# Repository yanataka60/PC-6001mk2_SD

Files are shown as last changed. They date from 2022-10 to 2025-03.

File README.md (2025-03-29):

# PC-6001mk2 MODE1～MODE4にSD-CARDからロード、セーブ機能

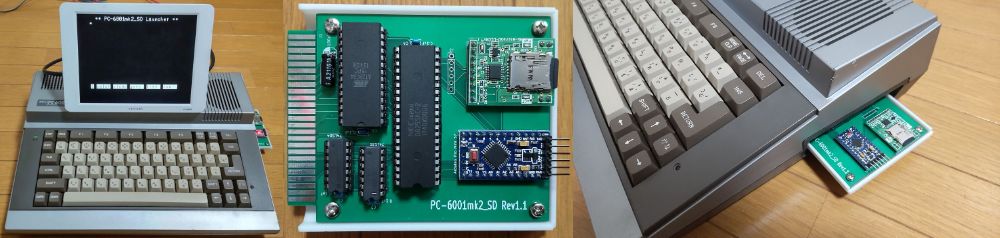
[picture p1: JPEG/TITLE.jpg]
TITLE


　PC-6001mk2の MODE1～MODE4でSD-CARDからロード、セーブ機能を実現するものです。

　対応機種は、PC-6001mk2、PC-6001mk2SR、PC-6601、PC-6601SRです。PC-6601、PC-6601SRはドライブ数切替スイッチは0として使ってください。

　対応しているCMT形式は、P6形式(拡張子はP6、CASのどちらでも大丈夫)とP6T形式です。

　CMTからの読み込み実行に数分掛かっていたゲームも数十秒で実行できます。

　なお、Arduino、ROMへ書き込むための機器が別途必要となります。

　また、本体内のBASIC-ROMを差し替えられるスキルがあればMODE5もSD対応にできます。詳細は、「MODE5対応について」を参照してください。

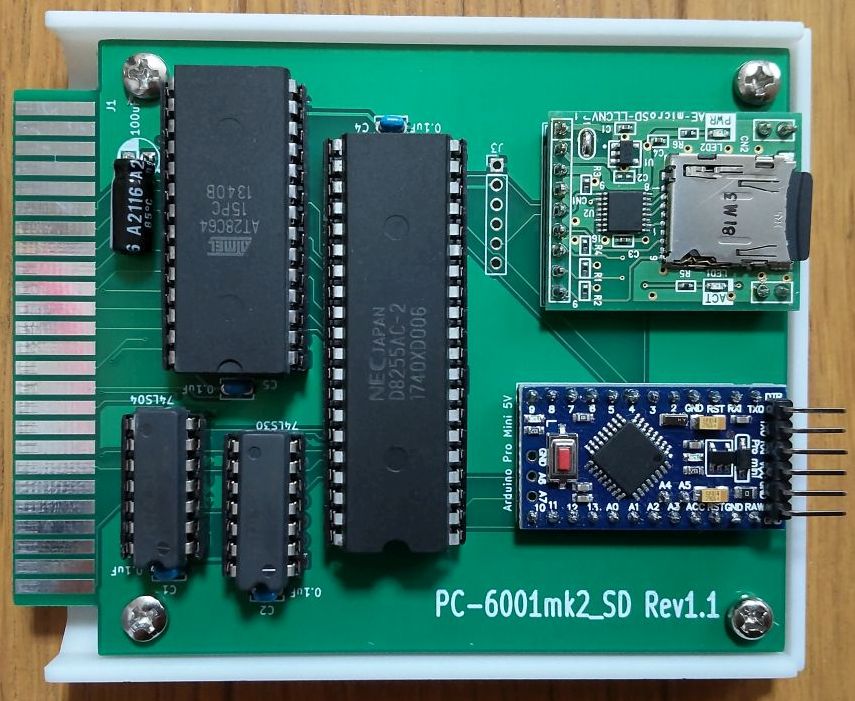
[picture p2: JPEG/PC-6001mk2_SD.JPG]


## 対応できないもの
　MODE1～MODE4については、BASIC-ROMを裏RAMにコピーしCMT関連ルーチンをSD-CARDアクセスに書き換えてSD-CARDへのアクセスを実現しています。

　MODE5についてはBASIC-ROMのCMT関連ルーチンにパッチを当てたROMに差し替えることでSD-CARDへのアクセスを実現していますが、MODE6についてはBASIC-ROMのCMT関連ルーチンが特定できていないためSD-CARDは使えません。

　また、BASIC-ROMのCMT関連ルーチンをコールせず独自ルーチンによりCMTからLOADするソフト（ロードランナー等）も対応できないので途中で止まります。

## 回路図
　KiCadフォルダ内のPC-6001mk2_SD.pdfを参照してください。

[回路図](https://github.com/yanataka60/PC-6001mk2_SD/blob/main/Kicad/PC-6001_mk2_SD.pdf)

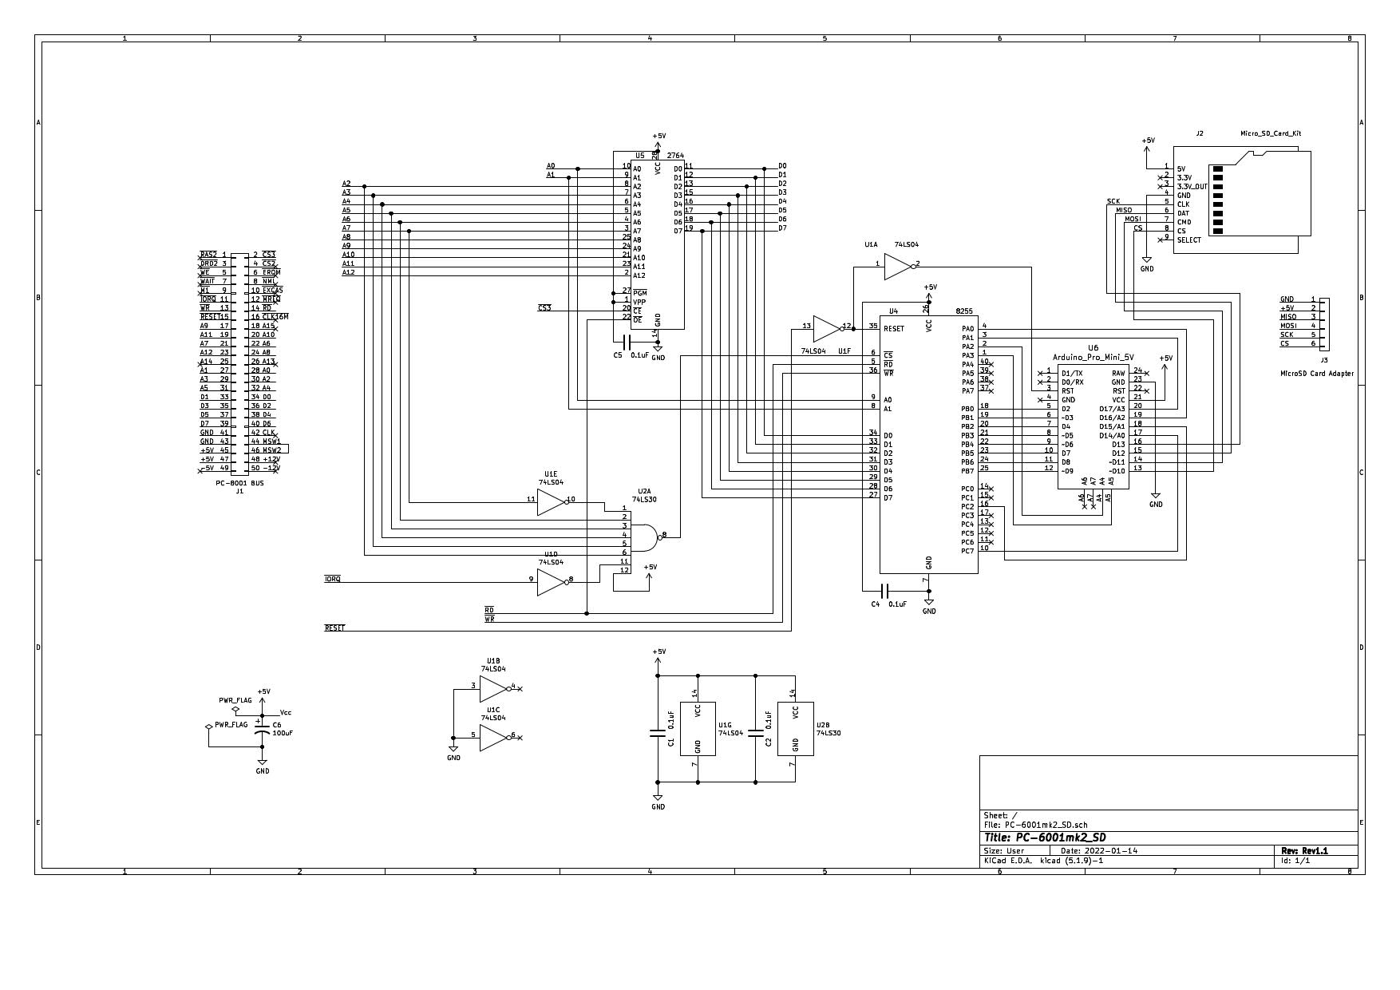
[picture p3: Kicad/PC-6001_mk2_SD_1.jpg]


## 部品
|番号|品名|数量|備考|
| --- | --- | --- | --- |
||J2、J3のいずれか(注1)|||
|J2|Micro_SD_Card_Kit|1|秋月電子通商 AE-microSD-LLCNV (注2)|
|J3|MicroSD Card Adapter|1|Arduino等に使われる5V電源に対応したもの (注4)|
|U1|74LS04|1||
|U2|74LS30|1||
|U4|8255|1||
|U5|2764/28C64相当品|1||
|U6|Arduino_Pro_Mini_5V|1|Atmega328版を使用 168版は不可。(注3)|
|C1 C2 C4 C5|積層セラミックコンデンサ 0.1uF|4||
|C6|電解コンデンサ 16v100uF|1||
||ピンヘッダ|2Pin分|Arduino_Pro_MiniにはA4、A5用のピンヘッダが付いていないため別途調達が必要です 秋月電子通商 PH-1x40SGなど|
||ピンソケット(任意)|26Pin分|Arduino_Pro_Miniを取り外し可能としたい場合に調達します 秋月電子通商 FHU-1x42SGなど|

　　　注1)J2又はJ3のどちらかを選択して取り付けてください。

　　　注2)秋月電子通商　AE-microSD-LLCNVのJ1ジャンパはショートしてください。

　　　注3)Arduino Pro MiniはA4、A5ピンも使っています。

　　　注4)MicroSD Card Adapterを使う場合

　　　　　J3に取り付けます。

　　　　　MicroSD Card Adapterについているピンヘッダを除去してハンダ付けするのが一番確実ですが、J3の穴にMicroSD Card Adapterをぴったりと押しつけ、裏から多めにハンダを流し込むことでハンダ付けをする方法もあります。なお、この方法の時にはしっかりハンダ付けが出来たかテスターで導通を確認しておいた方が安心です。

ハンダ付けに自信のない方はJ2の秋月電子通商　AE-microSD-LLCNVをお使いください。AE-microSD-LLCNVならパワーLED、アクセスLEDが付いています。

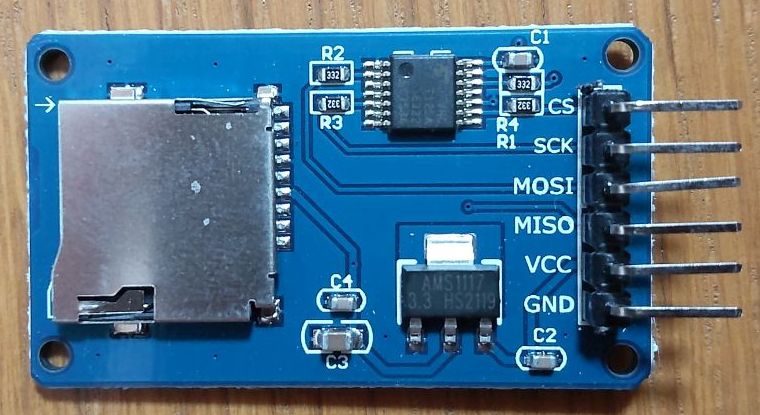
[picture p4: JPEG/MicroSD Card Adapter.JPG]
MicroSD Card Adapter1


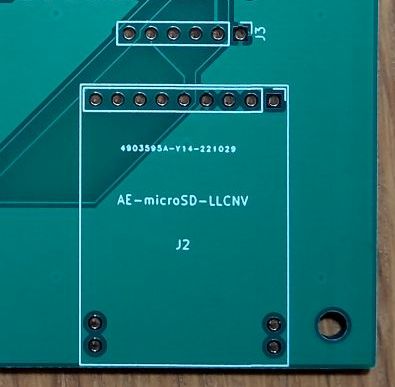
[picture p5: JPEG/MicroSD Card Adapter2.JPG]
MicroSD Card Adapter2


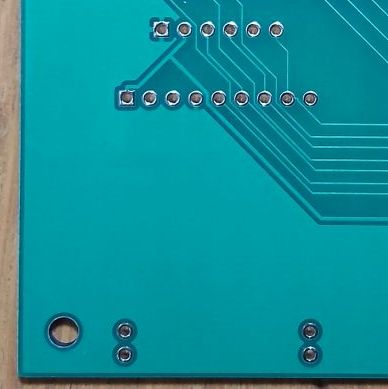
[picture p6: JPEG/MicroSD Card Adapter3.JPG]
MicroSD Card Adapter3


## ROMへの書込み
　Z80フォルダ内のEXT_ROM.binをROMライター(TL866II Plus等)を使って2764又は28C64に書き込みます。

## Arduinoプログラム
　Arduino IDEを使ってArduinoフォルダのPC-6001mk2_SDフォルダ内PC-6001mk2_SD.inoを書き込みます。

　SdFatライブラリを使用しているのでArduino IDEメニューのライブラリの管理からライブラリマネージャを立ち上げて「SdFat」をインストールしてください。

　「SdFat」で検索すれば見つかります。「SdFat」と「SdFat - Adafruit Fork」が見つかりますが「SdFat」のほうを使っています。

注)Arduinoを基板に直付けしている場合、Arduinoプログラムを書き込むときは、カートリッジスロットから抜き、74LS04を外したうえで書き込んでください。

## 接続
　カートリッジスロットに挿入します。

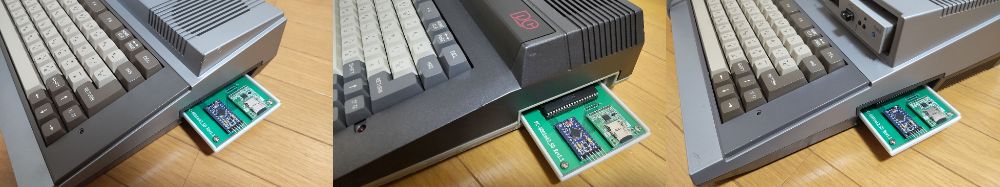
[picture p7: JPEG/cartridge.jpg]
cartridge


　カートリッジスロットへの抜き差しに基板のみでは不便です。

　STLフォルダに基板を載せられるトレイの3Dデータを置いたので出力して使うと便利です。

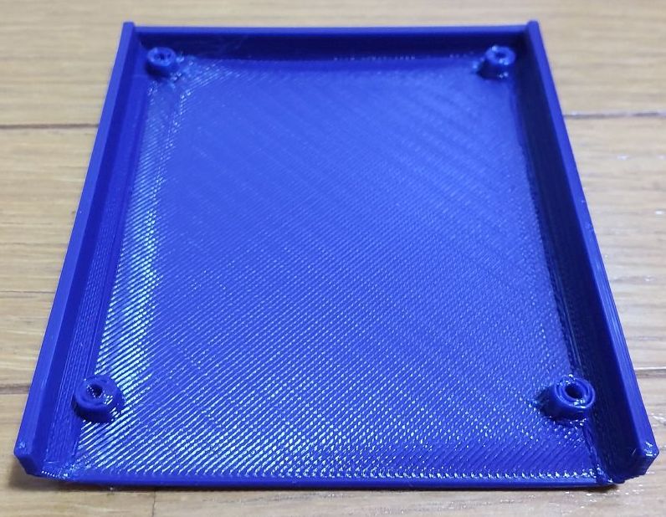
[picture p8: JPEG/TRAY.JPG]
Tray


　PC-6601、PC-6601SRはドライブ数切替スイッチは0として使ってください。

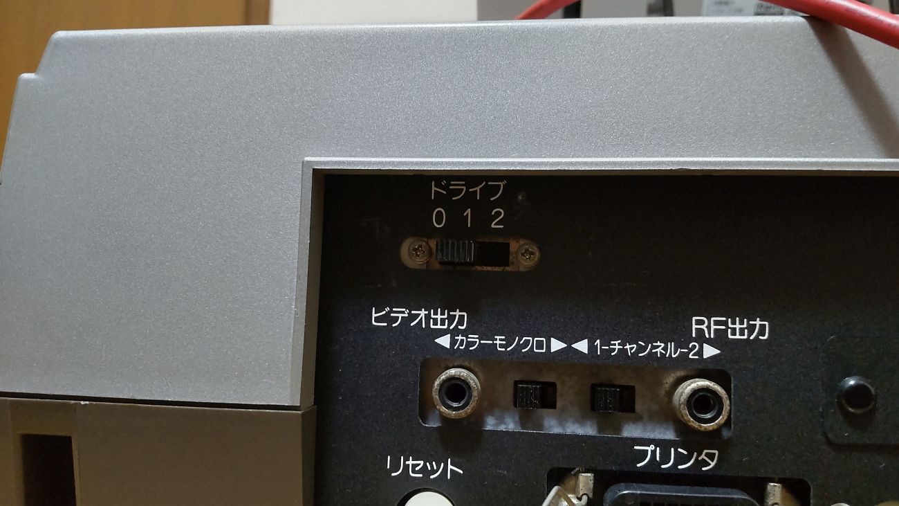
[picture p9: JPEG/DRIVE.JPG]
Drive


## SD-CARD
　出来れば8GB以下のSDカードを用意してください。

　ArduinoのSdFatライブラリは、SD規格(最大2GB)、SDHC規格(2GB～32GB)に対応していますが、SDXC規格(32GB～2TB)には対応していません。

　また、SDHC規格のSDカードであっても32GB、16GBは相性により動作しないものがあるようです。

　FAT16又はFAT32が認識できます。NTFSは認識できません。

　ルートに置かれた拡張子が「.P6T」又は「.CAS」の形式ファイルのみ認識できます。(以外のファイル、フォルダも表示されますがLOAD実行の対象になりません)

　ファイル名は拡張子を除いて32文字まで、ただし半角カタカナ、及び一部の記号はArduinoが認識しないので使えません。パソコンでファイル名を付けるときはアルファベット、数字および空白でファイル名をつけてください。

　起動直後の画面は横32文字表示です。拡張子を含めて27文字以下にしたほうが画面の乱れません。

## 使い方

起動直後は拡張ROMのプログラムが走り、以下のコマンドが使えます。

### Launcherコマンド
#### 1から4までのいずれかの後に[CR]
次に「How Many Pages?(1-4)」と聞いてくるので画面数を入力すると入力された数字のMODEと画面数でSD対応にして起動します。

#### B[CR]
SD対応せずにBASICを起動します。

[STOP]キーと動作は同じです。

#### [STOP]キー
SD対応せずにBASICを起動します。

B[CR]と動作は同じです。

#### F[CR]又はF 文字列[CR]
文字列を入力せずにF[CR]のみ入力するとSD-CARDルートディレクトリにあるファイルの一覧を表示します。

文字列を付けて入力すればSD-CARDルートディレクトリにあるその文字列から始まるファイルの一覧を表示します。

10件表示したところで指示待ちになるので打ち切るならESC又は↑を入力すると打ち切られ、Bキーで前の10件に戻ります。それ以外のキーで次の10件を表示します。

　行頭に「*L 」を付加して表示してあるので実行したいファイルにカーソルキーを合わせて[CR]キーを押すだけでLOAD可能です。

　LOADの挙動については次のLコマンドの記述を参照してください。

　表示される順番は、登録順となりファイル名アルファベッド順などのソートした順で表示することはできません。

##### 例)
　　F[CR]

　　F S[CR]

　　F SP[CR]

#### L DOSファイル名[CR]
指定したDOSフィル名のファイルをSD-CARDからLOADします。

ファイル名の最後の「.P6T」「.CAS」は有っても無くても構いませんが、無い場合は「.P6T」が指定されたものとみなします。

　例)

　　L TEST.P6T -> DOSファイル名「TEST.P6T」を読み込みます。

　　L TEST.CAS -> DOSファイル名「TEST.CAS」を読み込みます。

　　L TEST -> DOSファイル名「TEST.P6T」を読み込みます。

　選択したファイルが「P6T」形式の場合、設定されたMODEと設定されたPagesで起動したうえで自動実行文字列を実行します。

　選択したファイルが「CAS」形式の場合、「Mode?(1-4)」と聞いてくるのでモードを入力、次に「How Many Pages?(1-4)」と聞いてくるので画面数を入力、最後に「Auto Run?(y/c/n)」と聞いてくるので「y」とすれば起動直後にCLOAD[CR]RUN[CR]が実行され、「c」とすればCLOAD[CR]だけが実行、「n」とすれば何も実行されません。

#### 操作上の注意
　~~「SD-CARD INITIALIZE ERROR」と表示されたときは、SD-CARDをいったん抜き再挿入したうえでArduinoをリセットしてください。~~

　~~SD-CARDにアクセスしていない時に電源が入ったままで SD-CARDを抜いた後、再挿入しSD-CARDにアクセスすると「SD-CARD INITIALIZE ERROR」となる場合があります。再挿入した場合にはSD-CARDにアクセスする前にArduinoを必ずリセットしてください。~~

　~~SD-CARDの抜き差しは電源を切った状態で行うほうがより確実です。~~

　(2024.3.12) SD-CARDにアクセスしていない時に電源が入ったままでSD-CARDを抜くと再度SD-CARDを挿入してもSD-CARDにアクセスできない問題を解消しました。(Arduinoを最新版に書き換えてください)

　再度SD-CARDを挿入した後、Fコマンド、Lコマンド、CLOAD、CSAVE等でSD-CARDに3回ほどアクセスすれば復旧します。

### BASICコマンド
#### CLOAD "DOSファイル名"[CR]
指定したDOSフィル名のBASICプログラムをSD-CARDからLOADします。

ファイル名は6文字以内で必須です。6文字以上入力された場合には7文字以降は無視されます。ファイル名を入力せずにCLOAD[CR]とすると暴走します。

ファイル名の前に"(ダブルコーテーション)は必須ですが、ファイル名の後ろに"(ダブルコーテーション)は有っても無くても構いません。

ファイル名の最後に「.CAS」は必要ありません。「.CAS」が指定されたものとみなします。

　例)

　　CLOAD "TEST" -> DOSファイル名「TEST.CAS」を読み込みます。

　　CLOAD "TESTTEST" -> DOSファイル名「TESTTE.CAS」を読み込みます。

　　CLOAD "TEST.BAS.CMT" -> DOSファイル名「TEST.BA.CMT」を読み込みます。

#### CSAVE "DOSファイル名"[CR]
BASICプログラムを指定したDOSフィル名でSD-CARDに上書きSAVEします。

ファイル名は6文字以内で必須です。6文字以上入力された場合には7文字以降は無視されます。

ファイル名の前に"(ダブルコーテーション)は必須ですが、ファイル名の後ろに"(ダブルコーテーション)は有っても無くても構いません。

ファイル名の最後の「.CAS」は必要ありません。「.CAS」が指定されたものとみなします。

　例)

　　CSAVE "TEST" -> 「TEST.CAS」で保存される。

　　CSAVE "TESTTEST" -> 「TESTTE.CAS」で保存される。

## MODE5対応について(本体BASIC-ROMの差し替えが必要です、自己責任でお願いします)
　MODE5では裏RAMが使われるため、「BASIC-ROMを裏RAMにコピーしCMT関連ルーチンをSD-CARDアクセスに書き換え」が出来ませんのでSD-CARDアクセス用にパッチを当てたBASIC-ROMに差し替えることでMODE5に対応します。

　なお、市販ソフトでは2段目以降のCMTロードはBASIC-ROMを使わずに独自のロードルーチンを使っているものがあり、動かないことが多いです。

　雑誌打ち込みプログラムのロード、セーブ用と割り切ってください。

　また、本体ROMの抜き差し等において本体が故障又はBASIC-ROMが破損しても当方では責任をとれませんので自己責任で行ってください。

　本体BASIC-ROMの本体内の位置及びROM内容の吸出しに関しても自分で解決できる方のみ挑戦願います。

#### 従来MONITORのRコマンド未対応としていましたが、最初に何らかのBASICプログラムが無いと正常に読み込めないのが原因です。
#### 月刊マイコン '85/11月号掲載「サブマリン606」のように最初にCLOAD、次にMON、R-0とするプログラムは正常に読み込めます。
#### 未確認ですが、機械語だけをR-0で読み込むプログラムも最初になんらかのBASICプログラム(10 clearだけでも)をくっつけたp6ファイルに修正すればR-0で読み込み、Gxxxxで実行できると思います。

### Arduinoプログラム
　ArduinoフォルダのPC-6001mk2_SDフォルダ内PC-6001mk2_SD.inoと同じもので動作します。

### ROMへの書込み
　Z80フォルダ内のEXT_ROM.binと同じもので動作します。

### BASIC-ROMへのパッチあて
　以下のアドレスを修正します。

|ADDRESS|修正前|修正後|
| --- | --- | --- |
|1A61|C5 D5 E5|C3 12 58|
|1A70|C5 D5 E5|C3 15 58|
|1AB8|C5 D5 E5|C3 18 58|
|1ACC|C5 D5 E5|C3 1B 58|
|1B06|C5 D5 E5|C3 1E 58|

　MODE5フォルダ内のROM_PATCH.binの内容で5812H～5A20Hまでを差し替えます。

　この差し替えによりfilesが使えなくなり、FDDを繋いでいない限り問題はないと思うのですが、何かしらのサブルーチンをつぶしてしまっているかもしれません。

　リセットが掛かってしまう等が起きるソフトのSD起動は取り敢えず諦めてください。

　出来上がったバイナリを27256等に焼いて本体内ICソケットにそのまま差し替えると、CMT、FDDが使えなくなってしまうので27512等にオリジナルバイナリを前半、パッチ済みバイナリを後半に置いて焼き、27512のA15を5VとGNDにスイッチで切り替えられるようにし、オリジナルバイナリとパッチ済みバイナリを切り替えて使ってください。

## 謝辞
　基板の作成に当たり以下のデータを使わせていただきました。ありがとうございました。

　Arduino Pro Mini

　　https://github.com/g200kg/kicad-lib-arduino

　AE-microSD-LLCNV

　　https://github.com/kuninet/PC-8001-SD-8kRAM

## 追記
　2022.10.26 SD-CARDに対応できないハード、ソフトについて加筆しました。

　　　　　　 FコマンドにもDI追加。

　2022.10.27 MODE5対応テストについて追記しました。

　2022.10.28 MODE5対応テストで不具合の出る可能性を追記しました。あくまでテストですので了承ください。

　2022.10.29 CMTload終了処理にCMTsave終了エントリをCallしているソフトへの対策をArduinoプログラムに追加。MODE5用と統合。

　　　　　　 MODE5対応テストにおいてMONITOR Rコマンドには未対応であることを追記。

　2022.10.31 MODE5対応用にBASIC-ROMを差し替えるときには27512を使うことを追記。

　　　　　　 U5 2764用プログラムのMODE1～MODE4用とMODE5用を統合。統合に伴ってArduinoプログラムも修正。BASIC-ROMの内容がオリジナルであればMODE1～MODE4用、修正されていればMODE1～MODE5用として動作。

　　　　　　 BASIC-ROMを差し替えていなければ2764、Arduinoとも更新の必要なし。

　2023. 3. 4 MODE5においてMONITOR Rコマンドが機能するためには、最初に何らかのBASICプログラムが必要であることを追記。

　　　　　　 AUTO STARTの選択肢をy/c/nとし、CLOADも実行しない選択を追加

　　　　　　 CLOAD、CSAVEがLOAD、SAVEと誤表記されていたものを修正

　2024.1.15 SDカードは8GB以下が望ましいことを追記。

　2024.3.12 電源が入ったままでSD-CARDを抜くと再度SD-CARDを挿入してもSD-CARDにアクセスできない問題を解消した。

　2025.3.20 P6形式が使えることが伝わりにくい表記を修正した。

　2025.3.29 ピーガー伝説➋代さんにご指摘いただいた「LBUFをRS232Cバッファ」に修正。ファイルリスト表示時にB(前頁表示)を押し続けると期待した動作をしない、basic起動時にキーを押しているとOUTコマンドが正常に発行されないという問題が解消されます。

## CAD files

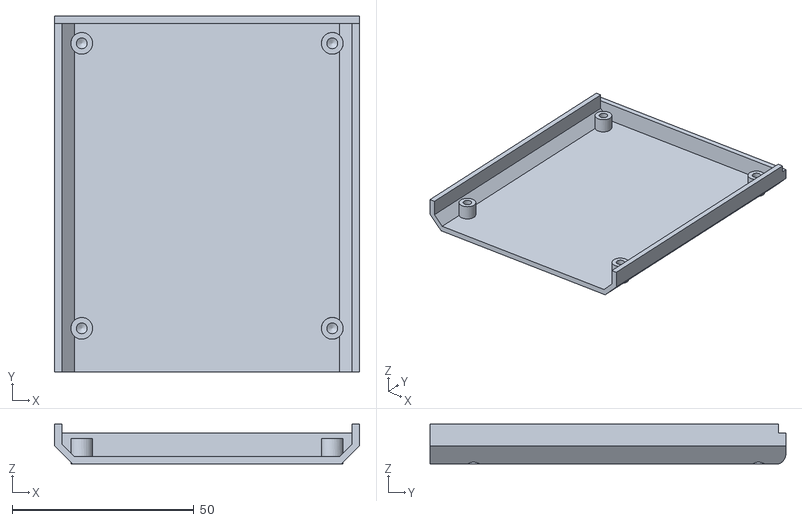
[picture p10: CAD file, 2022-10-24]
STL/PC-6001mk2_SD_tray.stl
84.0 x 98.0 x 11.0

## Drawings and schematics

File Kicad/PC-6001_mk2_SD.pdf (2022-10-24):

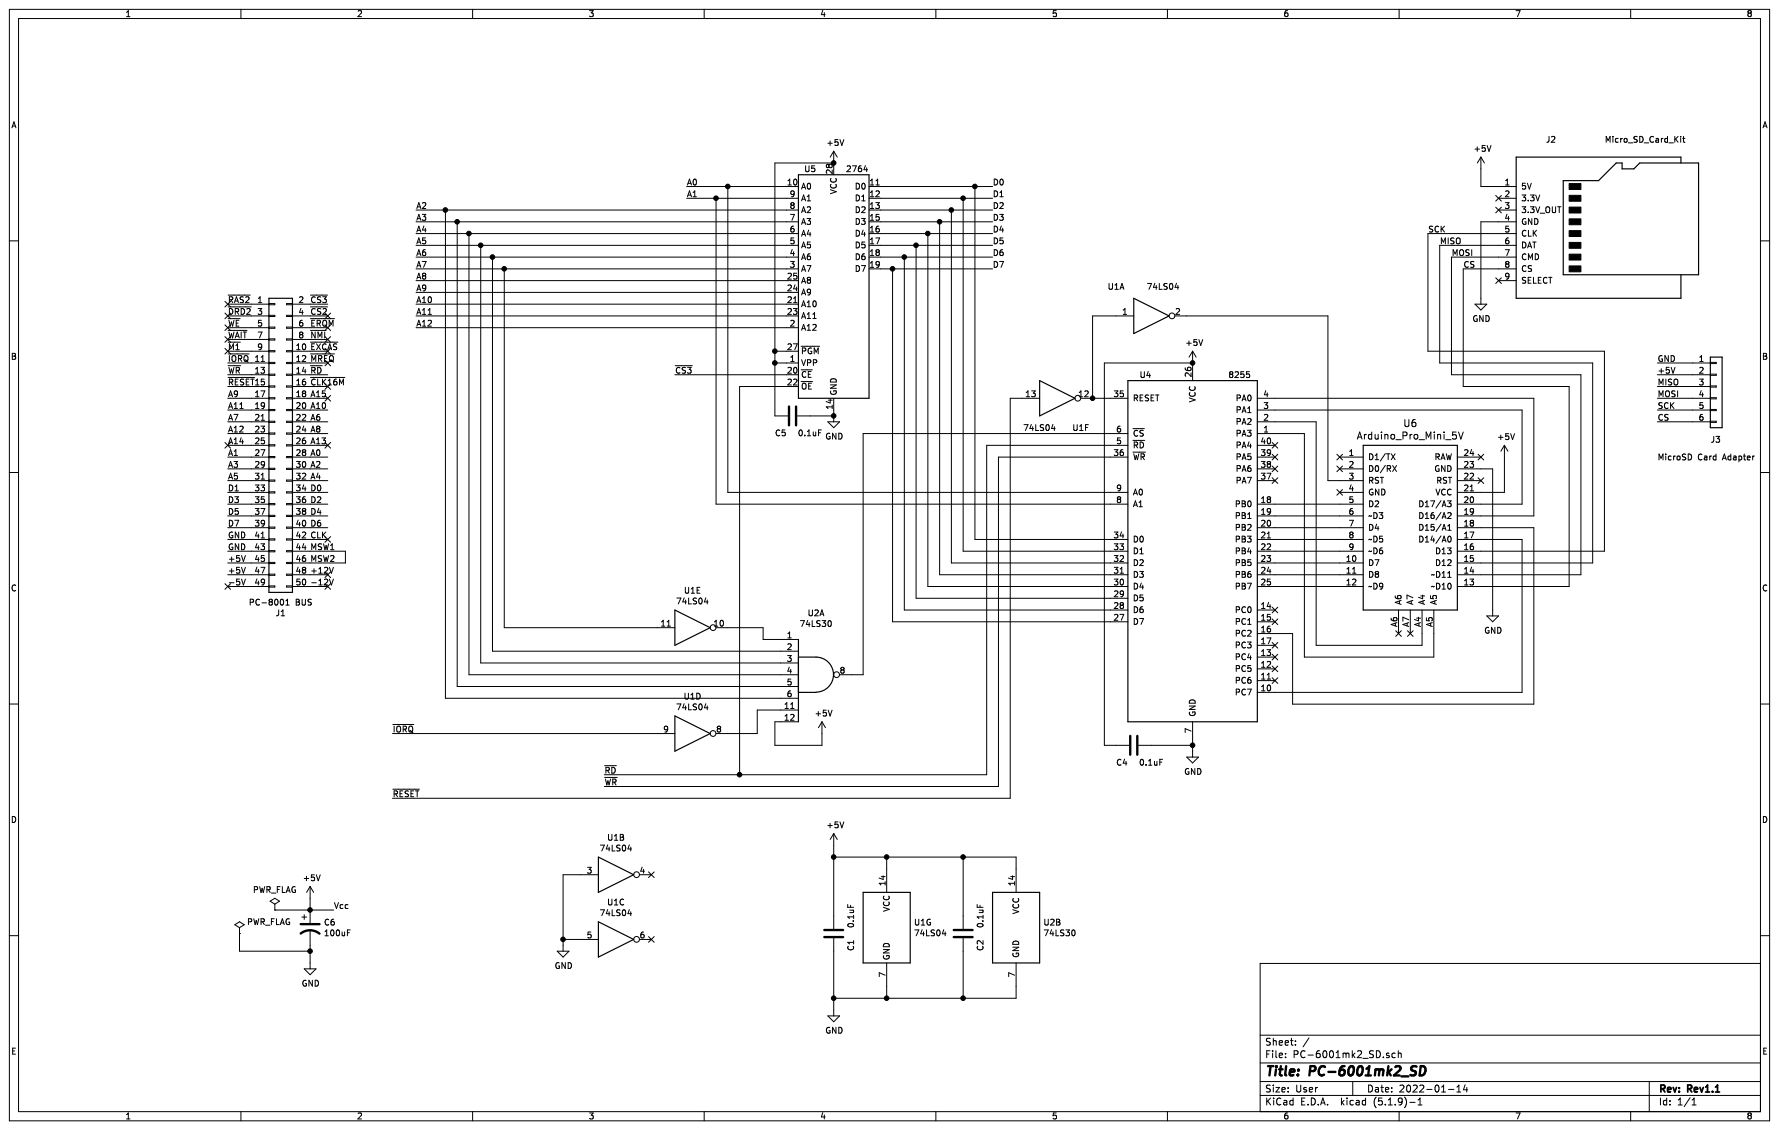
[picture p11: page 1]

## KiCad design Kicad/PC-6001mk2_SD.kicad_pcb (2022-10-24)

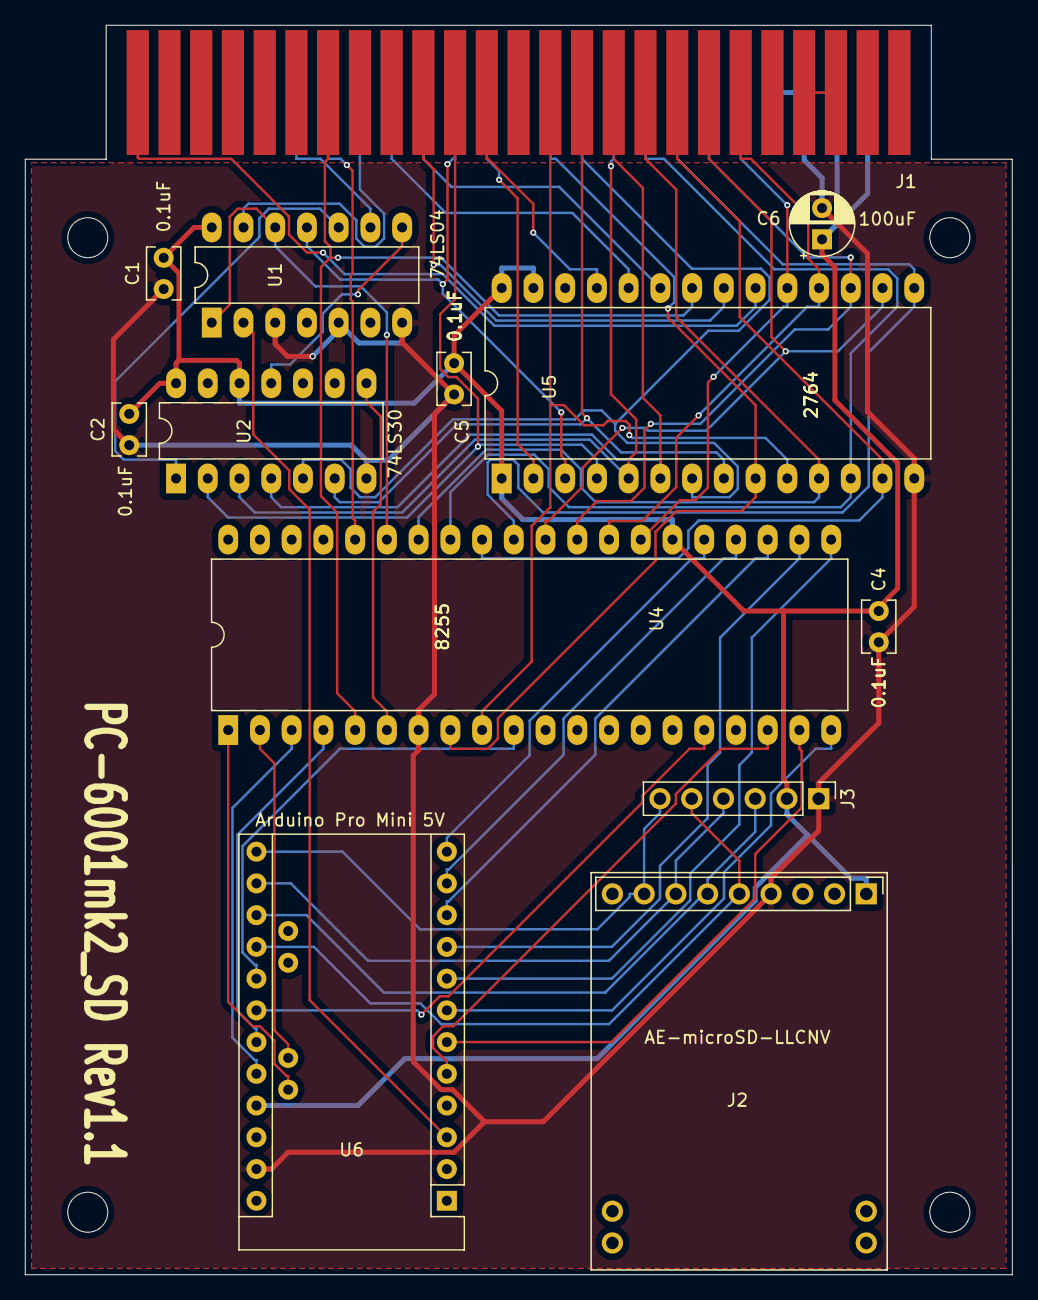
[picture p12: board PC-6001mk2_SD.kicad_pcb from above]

Board: 2 copper layers, 79.0 x 100.0 mm, 17 parts (0 on the bottom side), 52 nets.

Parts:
C1, C2, C4, C5: 0.1uF; C_Rect_L4.0mm_W2.5mm_P2.50mm
C6: 100uF; CP_Radial_D5.0mm_P2.50mm
J1: PC-8001 BUS; BUS_50Pin
J2: Micro_SD_Card_Kit; AE-microSD-LLCNV
J3: MicroSD Card Adapter; PinHeader_1x06_P2.54mm_Vertical
MH1, MH2, MH3, MH4: MountingHole_3.2mm_M3
U1: 74LS04; DIP-14_W7.62mm_LongPads
U2: 74LS30; DIP-14_W7.62mm_LongPads
U4: 8255; DIP-40_W15.24mm_LongPads
U5: 2764; DIP-28_W15.24mm_LongPads
U6: Arduino_Pro_Mini_5V; Arduino_Pro_Mini

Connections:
+5V: C1.2, C2.2, C4.1, C5.1, C6.1, J1.45, J1.47, J2.1, J3.2, U1.14, U2.12, U2.14, U4.26, U5.1, U5.27, U5.28, U6.21
/A0: J1.28, U4.9, U5.10
/A1: J1.27, U4.8, U5.9
/A2: J1.30, U2.6, U5.8
/A3: J1.29, U2.5, U5.7
/A4: J1.32, U2.4, U5.6
/A5: J1.31, U2.3, U5.5
/A6: J1.22, U2.2, U5.4
/A7: J1.21, U1.11, U5.3
/A8: J1.24, U5.25
/A9: J1.17, U5.24
/A10: J1.20, U5.21
/A11: J1.19, U5.23
/A12: J1.23, U5.2
/CS: J2.8, J3.6, U6.13
/D0: J1.34, U4.34, U5.11
/D1: J1.33, U4.33, U5.12
/D2: J1.36, U4.32, U5.13
/D3: J1.35, U4.31, U5.15
/D4: J1.38, U4.30, U5.16
/D5: J1.37, U4.29, U5.17
/D6: J1.40, U4.28, U5.18
/D7: J1.39, U4.27, U5.19
/MISO: J2.6, J3.3, U6.15
/MOSI: J2.7, J3.4, U6.14
/MSW1: J1.44, J1.46
/SCK: J2.5, J3.5, U6.16
/~CS3: J1.2, U5.20
/~IORQ: J1.11, U1.9
/~RD: J1.14, U4.5, U5.22
/~RESET: J1.15, U1.13
/~WR: J1.13, U4.36
GND: C1.1, C2.1, C4.2, C5.2, C6.2, J1.41, J1.43, J2.4, J3.1, U1.3, U1.5, U1.7, U2.7, U4.7, U5.14, U6.23
unnamed: U1.1, U1.12, U4.35
unnamed: U1.2, U6.3
unnamed: U1.8, U2.11
unnamed: U1.10, U2.1
unnamed: U2.8, U4.6
unnamed: U4.1, U6.A5
unnamed: U4.2, U6.A4
unnamed: U4.3, U6.20
unnamed: U4.4, U6.19
unnamed: U4.10, U6.17
unnamed: U4.16, U6.18
unnamed: U4.18, U6.5
unnamed: U4.19, U6.6
unnamed: U4.20, U6.7
unnamed: U4.21, U6.8
unnamed: U4.22, U6.9
unnamed: U4.23, U6.10
unnamed: U4.24, U6.11
unnamed: U4.25, U6.12

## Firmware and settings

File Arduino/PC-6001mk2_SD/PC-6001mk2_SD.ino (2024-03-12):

//2022.10.28 CMTload終了処理にCMTsave終了エントリをCallしているソフトへの対策にsave_flg追加。
//2022.10.31 MODE5を許可
//2024. 3.12 sd-card再挿入時の初期化処理を追加
#include "SdFat.h"
#include <SPI.h>
SdFat SD;
unsigned long r_count=0,s_count=0;
unsigned long f_length=0;
char m_name[40];
byte s_data[260];
char f_name[40];
char c_name[40];
char new_name[40];
char as_str[80];
File file;
unsigned int s_adrs,e_adrs,w_length,w_len1,w_len2,s_adrs1,s_adrs2,b_length,b_mode,b_page,as_len;
boolean eflg,basic_d3,save_flg;

#define CABLESELECTPIN  (10)
#define CHKPIN          (15)
#define PB0PIN          (2)
#define PB1PIN          (3)
#define PB2PIN          (4)
#define PB3PIN          (5)
#define PB4PIN          (6)
#define PB5PIN          (7)
#define PB6PIN          (8)
#define PB7PIN          (9)
#define FLGPIN          (14)
#define PA0PIN          (16)
#define PA1PIN          (17)
#define PA2PIN          (18)
#define PA3PIN          (19)
// ファイル名は、ロングファイルネーム形式対応

void sdinit(void){
  // SD初期化
  if( !SD.begin(CABLESELECTPIN,8) )
  {
////    Serial.println("Failed : SD.begin");
    eflg = true;
  } else {
////    Serial.println("OK : SD.begin");
    eflg = false;
  }
////    Serial.println("START");
}

void setup(){
////    Serial.begin(9600);
// CS=pin10
// pin10 output

  pinMode(CABLESELECTPIN,OUTPUT);
  pinMode( CHKPIN,INPUT);  //CHK
  pinMode( PB0PIN,OUTPUT); //送信データ
  pinMode( PB1PIN,OUTPUT); //送信データ
  pinMode( PB2PIN,OUTPUT); //送信データ
  pinMode( PB3PIN,OUTPUT); //送信データ
  pinMode( PB4PIN,OUTPUT); //送信データ
  pinMode( PB5PIN,OUTPUT); //送信データ
  pinMode( PB6PIN,OUTPUT); //送信データ
  pinMode( PB7PIN,OUTPUT); //送信データ
  pinMode( FLGPIN,OUTPUT); //FLG

  pinMode( PA0PIN,INPUT_PULLUP); //受信データ
  pinMode( PA1PIN,INPUT_PULLUP); //受信データ
  pinMode( PA2PIN,INPUT_PULLUP); //受信データ
  pinMode( PA3PIN,INPUT_PULLUP); //受信データ

  digitalWrite(PB0PIN,LOW);
  digitalWrite(PB1PIN,LOW);
  digitalWrite(PB2PIN,LOW);
  digitalWrite(PB3PIN,LOW);
  digitalWrite(PB4PIN,LOW);
  digitalWrite(PB5PIN,LOW);
  digitalWrite(PB6PIN,LOW);
  digitalWrite(PB7PIN,LOW);
  digitalWrite(FLGPIN,LOW);

  delay(500);

  sdinit();
}

//4BIT受信
byte rcv4bit(void){
//HIGHになるまでループ
  while(digitalRead(CHKPIN) != HIGH){
  }
//受信
  byte j_data = digitalRead(PA0PIN)+digitalRead(PA1PIN)*2+digitalRead(PA2PIN)*4+digitalRead(PA3PIN)*8;
//FLGをセット
  digitalWrite(FLGPIN,HIGH);
//LOWになるまでループ
  while(digitalRead(CHKPIN) == HIGH){
  }
//FLGをリセット
  digitalWrite(FLGPIN,LOW);
  return(j_data);
}

//1BYTE受信
byte rcv1byte(void){
  byte i_data = 0;
  i_data=rcv4bit()*16;
  i_data=i_data+rcv4bit();
  return(i_data);
}

//1BYTE送信
void snd1byte(byte i_data){
//下位ビットから8ビット分をセット
  digitalWrite(PB0PIN,(i_data)&0x01);
  digitalWrite(PB1PIN,(i_data>>1)&0x01);
  digitalWrite(PB2PIN,(i_data>>2)&0x01);
  digitalWrite(PB3PIN,(i_data>>3)&0x01);
  digitalWrite(PB4PIN,(i_data>>4)&0x01);
  digitalWrite(PB5PIN,(i_data>>5)&0x01);
  digitalWrite(PB6PIN,(i_data>>6)&0x01);
  digitalWrite(PB7PIN,(i_data>>7)&0x01);
  digitalWrite(FLGPIN,HIGH);
//HIGHになるまでループ
  while(digitalRead(CHKPIN) != HIGH){
  }
  digitalWrite(FLGPIN,LOW);
//LOWになるまでループ
  while(digitalRead(CHKPIN) == HIGH){
  }
}

//小文字->大文字
char upper(char c){
  if('a' <= c && c <= 'z'){
    c = c - ('a' - 'A');
  }
  return c;
}

//ファイル名の最後が「.p6t」でなければ付加
void addp6t(char *f_name,char *m_name){
  unsigned int lp1=0;
  while (f_name[lp1] != 0x00){
    m_name[lp1] = f_name[lp1];
    lp1++;
  }
  if (f_name[lp1-4]!='.' ||
    ( f_name[lp1-3]!='P' &&
      f_name[lp1-3]!='p' ) ||
    ( f_name[lp1-2]!='6' ) ||
    ( f_name[lp1-1]!='T' &&
      f_name[lp1-1]!='t' ) ){
         m_name[lp1++] = '.';
         m_name[lp1++] = 'p';
         m_name[lp1++] = '6';
         m_name[lp1++] = 't';
  }
  m_name[lp1] = 0x00;
}

//ファイル名の最後が「.p6」ならそのまま、「.p6」でもなく「.cas」でもなければ「.cas」を付加
void addcas(char *f_name,char *m_name){
  unsigned int lp1=0;
  while (f_name[lp1] != 0x00){
    m_name[lp1] = f_name[lp1];
    lp1++;
  }
  if ( ( f_name[lp1-3]!='.') ||
       ( f_name[lp1-2]!='P' &&
         f_name[lp1-2]!='p' ) ||
       ( f_name[lp1-1]!='6') ){
    if (f_name[lp1-4]!='.' ||
      ( f_name[lp1-3]!='c' &&
        f_name[lp1-3]!='C' ) ||
      ( f_name[lp1-2]!='a' &&
        f_name[lp1-2]!='A' ) ||
      ( f_name[lp1-1]!='s' &&
        f_name[lp1-1]!='S' ) ){
           m_name[lp1++] = '.';
           m_name[lp1++] = 'c';
           m_name[lp1++] = 'a';
           m_name[lp1++] = 's';
    }
  }
  m_name[lp1] = 0x00;
}

//比較文字列取得 32+1文字まで取得、ただしダブルコーテーションは無視する
void receive_name(char *f_name){
char r_data;
  unsigned int lp2 = 0;
  for (unsigned int lp1 = 0;lp1 <= 32;lp1++){
    r_data = rcv1byte();
    if (r_data != 0x22){
      f_name[lp2] = r_data;
      lp2++;
    }
  }
}

// p6 LOADコマンド .p6 LOAD
void P6_load(void){
  boolean flg = false;
//DOSファイル名取得
  receive_name(m_name);
  addcas(m_name,f_name);
//ファイルが存在しなければERROR
  if (SD.exists(f_name) == true){
//    if (f_length != r_count){
//      file.close();
//    }
//ファイルオープン
    file = SD.open( f_name, FILE_READ );

    if( true == file ){
//f_length設定、r_count初期化
      f_length = file.size();
      r_count = 0;
//2022.10.28 CMTload終了処理にCMTsave終了エントリをCallしているソフトへの対策にsave_flg追加。
      save_flg=false;
//状態コード送信(OK)
      snd1byte(0x00);
      flg = true;
    } else {
      snd1byte(0xf0);
      sdinit();
      flg = false;
    }
  }else{
    snd1byte(0xf1);
    sdinit();
    flg = false;
  }
}

// p6t LOADコマンド .p6t LOAD
void cmt_load(void){
  boolean flg = false;
//DOSファイル名取得
  receive_name(m_name);
//ファイル名の指定があるか
  if (m_name[0]!=0x00){
    addp6t(m_name,f_name);
  
//指定があった場合
//ファイルが存在しなければERROR
    if (SD.exists(f_name) == true){
//      if (f_length != r_count){
//        file.close();
//      }
//ファイルオープン
      file = SD.open( f_name, FILE_READ );

      if( true == file ){
//f_length設定、r_count初期化
        f_length = file.size();
        r_count = 0;
//2022.10.28 CMTload終了処理にCMTsave終了エントリをCallしているソフトへの対策にsave_flg追加。
        save_flg=false;
//状態コード送信(OK)
        snd1byte(0x00);
        flg = true;
      } else {
        snd1byte(0xf0);
        sdinit();
        flg = false;
      }
    }else{
      snd1byte(0xf1);
      sdinit();
      flg = false;
    }
    if (flg == true){
//p6t_info取得
        p6t_info();
    }
  }
}

//p6tファイルからMODE、FILES、自動実行文字列を抽出
void p6t_info(void){
//f_length設定、r_count初期化
  f_length = file.size();
  r_count = 2;
  if ((file.read()=='P') && (file.read()=='6')){
// v1なら先頭に付加されている
    p6t_v1();
  } else{
// v2は最後に付いている
    p6t_v2();
  }
}

//p6t v1ファイルからMODE、FILES、自動実行文字列を抽出
void p6t_v1(void){
  int rdata = 0;
  snd1byte(0x00); 
  rdata=file.read();
  r_count++;
  rdata=file.read();
  r_count++;
//BASICモード
  b_mode = file.read();
  r_count++;
  snd1byte(b_mode);
////  Serial.println(b_mode,HEX);
//// MODE1～MODE5の時だけ実行可
  if(b_mode!=0 && b_mode!=6){
//ページ数
    b_page = file.read();
    r_count++;
    snd1byte(b_page);
////  Serial.println(b_page,HEX);
//オートスタートコマンド文字数(2Byte目は読み飛ばし,80文字以上は想定しない)
    as_len = file.read();
    r_count++;
    rdata = file.read();
    r_count++;
    snd1byte(as_len);
////  Serial.println(as_len);
//オートスタート文字列取得
    int lp1=0;
    while (lp1<as_len){
      as_str[lp1]=file.read();
      r_count++;
      snd1byte(as_str[lp1]);
////    Serial.print(as_str[lp1],HEX);
      lp1++;
    }
    as_str[lp1]=0x00;
////  Serial.println();
////  Serial.println(as_str);
//BASICヘッダーが出てくるまで読み飛ばし
    while (rdata != 0xd3) {
      rdata = file.read();
      r_count++;
    }
    r_count--;
    file.seek(r_count);
  }
}

//p6t v2ファイルからMODE、FILES、自動実行文字列を抽出
void p6t_v2(void){
  int rdata = 0;
  int rdata2 = 0;
  int zcnt = 0;
  int zdata = 1;
  boolean flg = true;
////  Serial.println("check 1");
//識別子'P6'の'P'が出てくるまで読み飛ばし
  while (rdata != 'P' && flg == true) {
//まずBASICヘッダーが出てくるまで読み飛ばし
    while (rdata != 0xd3) {
      rdata = file.read();
      r_count++;
    }
////  Serial.println("check 2");
    zcnt = 0;
    zdata = 1;
//プログラムエンド(0x00が9個続く)まで読み飛ばし
    while (zcnt < 9) {
      rdata = file.read();
      r_count++;
      if (rdata == 0x00){
        zcnt++;
        if (zdata != 0){
          zcnt = 0;
        }
      }
      zdata = rdata;
    }
////  Serial.println("check 3");
    rdata = 0;
    rdata2 = 0;
    zcnt = 0;
    zdata = 0;
//識別子'P6'又は次のブロックのヘッダー(0xd3が9個続く)が出てくるまで読み飛ばし
    while (!(rdata == 'P' && rdata2 == '6') && zcnt < 9 && flg == true) {
//    while (!(rdata == 'P' && rdata2 == '6')) {
      rdata = rdata2;
      rdata2 = file.read();
      r_count++;
      if (rdata2 == 0xd3){
        zcnt++;
        if (zdata != 0xd3){
          zcnt = 0;
        }
      }
      zdata = rdata2;
////      Serial.println(rdata2,HEX);
      if (r_count >= f_length){
        flg = false;
      }
    }
  }
  if (flg == true){
    snd1byte(0x00); 

////  Serial.println("check 4");
//p6tバージョン読み飛ばし
    rdata = file.read();
//含まれるDATAブロック数読み飛ばし
    rdata = file.read();
//オートスタートフラグ(0:無効 1:有効)読み飛ばし(有効固定)
    rdata = file.read();
//BASICモード
    b_mode = file.read();
    snd1byte(b_mode);
////  Serial.println(b_mode,HEX);
//// MODE1～MODE5の時だけ実行可
    if(b_mode!=0 && b_mode!=6){
//ページ数
      b_page = file.read();
      snd1byte(b_page);
////  Serial.println(b_page,HEX);
//オートスタートコマンド文字数(2Byte目は読み飛ばし,80文字以上は想定しない)
      as_len = file.read();
      rdata = file.read();
      snd1byte(as_len);
////  Serial.println(as_len);
//オートスタート文字列取得
      int lp1=0;
      while (lp1<as_len){
        as_str[lp1]=file.read();
        snd1byte(as_str[lp1]);
////    Serial.print(as_str[lp1],HEX);
        lp1++;
      }
      as_str[lp1]=0x00;
////  Serial.println();
////  Serial.println(as_str);
      file.seek(0);
      r_count = 0;
    }
  } else{
    snd1byte(0xf0);
    file.seek(0);
    r_count = 0;
  }
}

//LOAD ONE BYTE、OPENしているファイルの続きから1Byteを読み込み、送信
void load1byte(void){
  int rdata = file.read();
  r_count++;
  snd1byte(rdata);

////  Serial.print("f_length:");
////  Serial.print(f_length);
////  Serial.print(" r_count:");
////  Serial.print(r_count);
////  Serial.print(" rdata:");
////  Serial.println(rdata,HEX);

//ファイルエンドまで達していればFILE CLOSE
  if (f_length == r_count){
    file.close();
  }      
}

// SD-CARDのFILELIST
void dirlist(void){
//比較文字列取得 32+1文字まで

  for (unsigned int lp1 = 0;lp1 <= 32;lp1++){
    c_name[lp1] = rcv1byte();
  }
//
  File file = SD.open( "/" );
  if( true == file ){
//状態コード送信(OK)
    snd1byte(0x00);

    File entry =  file.openNextFile();
    int cntl2 = 0;
    unsigned int br_chk =0;
    int page = 1;
//全件出力の場合には10件出力したところで一時停止、キー入力により継続、打ち切りを選択
    while (br_chk == 0) {
      if(entry){
        entry.getName(f_name,36);
        unsigned int lp1=0;
//一件送信
//比較文字列でファイルネームを先頭10文字まで比較して一致するものだけを出力
        if (f_match(f_name,c_name)){
          while (lp1<=36 && f_name[lp1]!=0x00){
          snd1byte(upper(f_name[lp1]));
          lp1++;
          }
          snd1byte(0x0D);
          snd1byte(0x00);
          cntl2++;
        }
      }
      if (!entry || cntl2 > 9){
//継続・打ち切り選択指示要求
        snd1byte(0xfe);

//選択指示受信(0:継続 B:前ページ 以外:打ち切り)
        br_chk = rcv1byte();
//前ページ処理
        if (br_chk==0x42){
//先頭ファイルへ
          file.rewindDirectory();
//entry値更新
          entry =  file.openNextFile();
//もう一度先頭ファイルへ
          file.rewindDirectory();
          if(page <= 2){
//現在ページが1ページ又は2ページなら1ページ目に戻る処理
            page = 0;
          } else {
//現在ページが3ページ以降なら前々ページまでのファイルを読み飛ばす
            page = page -2;
            cntl2=0;
            while(cntl2 < page*10){
              entry =  file.openNextFile();
              if (f_match(f_name,c_name)){
                cntl2++;
              }
            }
          }
          br_chk=0;
        }
        page++;
        cntl2 = 0;
      }
//ファイルがまだあるなら次読み込み、なければ打ち切り指示
      if (entry){
        entry =  file.openNextFile();
      }else{
        br_chk=1;
      }
//FDLの結果が10件未満なら継続指示要求せずにそのまま終了
      if (!entry && cntl2 < 10 && page ==1){
        break;
      }
    }
//処理終了指示
    snd1byte(0xFF);
    snd1byte(0x00);
  }else{
    snd1byte(0xf1);
  }
}

//f_nameとc_nameをc_nameに0x00が出るまで比較
//FILENAME COMPARE
boolean f_match(char *f_name,char *c_name){
  boolean flg1 = true;
  unsigned int lp1 = 0;
  while (lp1 <=32 && c_name[0] != 0x00 && flg1 == true){
    if (upper(f_name[lp1]) != c_name[lp1]){
      flg1 = false;
    }
    lp1++;
    if (c_name[lp1]==0x00){
      break;
    }
  }
  return flg1;
}

//BASICプログラムのSAVE開始処理
void bas_save_ini(void){
//DOSファイル名取得
////  Serial.println("test1");
  receive_name(m_name);
////  Serial.println(m_name);
//ファイル名の指定が無ければエラー
  if (m_name[0]!=0x00){
    addcas(m_name,f_name);
////  Serial.println(f_name);
  
//ファイルが存在すればdelete
    if (SD.exists(f_name) == true){
      SD.remove(f_name);
    }
//ファイルオープン
    file = SD.open( f_name, FILE_WRITE );
    if( true == file ){
      s_count=0;
      basic_d3=false;
//2022.10.28 CMTload終了処理にCMTsave終了エントリをCallしているソフトへの対策にsave_flg追加。
      save_flg=true;
//状態コード送信(OK)
      snd1byte(0x00);
    } else {
      snd1byte(0xf0);
      sdinit();
    }
  }else{
    snd1byte(0xf1);
    sdinit();
  }
}

//BASICプログラムの1Byte受信処理
void save1byte(void){
//1Byte受信、書き込み
    int rdata = rcv1byte();
    s_count++;
    if(s_count==1 && rdata==0xd3){
      basic_d3=true;
    }else{
      if(s_count<11 && basic_d3==true && rdata==0x00){
        rdata=0xd3;
      }
    }
    file.write(rdata);
    
////  Serial.println(rdata,HEX);
//  file.write(rcv1byte());
  
}

//BASICプログラムのSAVE終了処理
void bas_save_end(void){
//2022.10.28 CMTload終了処理にCMTsave終了エントリをCallしているソフトへの対策にsave_flg追加。save_flgがtrueの時だけファイルクローズ。
  if (save_flg == true){
    file.close();
  }
}

//BASICプログラムのLOAD処理
void bas_load(void){
  boolean flg = false;
//DOSファイル名取得
  receive_name(m_name);
//ファイル名の指定があるか
  if (m_name[0]!=0x00){
    addp6t(m_name,f_name);
  
//指定があった場合
//ファイルが存在しなければERROR
    if (SD.exists(f_name) == true){
//ファイルオープン
      file = SD.open( f_name, FILE_READ );
      if( true == file ){
//f_length設定、r_count初期化
        f_length = file.size();
        r_count = 0;
//2022.10.28 CMTload終了処理にCMTsave終了エントリをCallしているソフトへの対策にsave_flg追加。
        save_flg=false;
//状態コード送信(OK)
        snd1byte(0x00);
        flg = true;
      } else {
        snd1byte(0xf0);
        sdinit();
        flg = false;
      }
    }else{
      snd1byte(0xf1);
      sdinit();
      flg = false;
    }
  } else{
//ファイル名の指定がなかった場合
//ファイルエンドになっていないか
    if (f_length > r_count){
      snd1byte(0x00);
      flg = true;
    }else{
      snd1byte(0xf1);
      sdinit();
      flg = false;
    }
  }
//良ければファイルエンドまで読み込みを続行する
  if (flg == true){
    int rdata = 0;
      
//ヘッダーが出てくるまで読み飛ばし
    while (rdata != 0x3a && rdata != 0xd3) {
      rdata = file.read();
      r_count++;
    }
//ヘッダー送信
    snd1byte(rdata);
//ヘッダーが0xd3なら続行、違えばエラー
    if (rdata == 0xd3){
      while (rdata == 0xd3) {
        rdata = file.read();
        r_count++;
      }

//実データ送信
      int zcnt = 0;
      int zdata = 1;

      snd1byte(rdata);

//0x00が11個続くまで読み込み、送信
      while (zcnt < 11) {
        rdata = file.read();
        r_count++;
        snd1byte(rdata);
        if (rdata == 0x00){
          zcnt++;
          if (zdata != 0){
            zcnt = 0;
          }
        }
        zdata = rdata;
      }

//ファイルエンドに達していたらFILE CLOSE
      if (f_length == r_count){
        file.close();
      }      
    }else{
        file.close();
    }
  }
}

//BASICプログラムのKILL処理
void bas_kill(void){
unsigned int lp1;

//DOSファイル名取得
  receive_name(m_name);
//ファイル名の指定が無ければエラー
  if (m_name[0]!=0x00){
    addp6t(m_name,f_name);
  
//状態コード送信(OK)
      snd1byte(0x00);
//ファイルが存在すればdelete
    if (SD.exists(f_name) == true){
      SD.remove(f_name);
//状態コード送信(OK)
      snd1byte(0x00);
    }else{
      snd1byte(0xf1);
      sdinit();
    }
  }else{
    snd1byte(0xf1);
    sdinit();
  }
}


void loop()
{
  digitalWrite(PB0PIN,LOW);
  digitalWrite(PB1PIN,LOW);
  digitalWrite(PB2PIN,LOW);
  digitalWrite(PB3PIN,LOW);
  digitalWrite(PB4PIN,LOW);
  digitalWrite(PB5PIN,LOW);
  digitalWrite(PB6PIN,LOW);
  digitalWrite(PB7PIN,LOW);
  digitalWrite(FLGPIN,LOW);
//コマンド取得待ち
////    Serial.println("COMMAND WAIT");
  byte cmd = rcv1byte();
////    Serial.println(cmd,HEX);
  if (eflg == false){
    switch(cmd) {
//61hでファイルリスト出力
      case 0x61:
////    Serial.println("FILE LIST START");
//状態コード送信(OK)
        snd1byte(0x00);
        sdinit();
        dirlist();
        break;
//62h:PC-6001 p6tファイル LOAD
      case 0x62:
////    Serial.println("p6t LOAD START");
//状態コード送信(OK)
        snd1byte(0x00);
        cmt_load();
////  delay(1500);
        break;
//63h:PC-6001 P6ファイル LOAD
      case 0x63:
////    Serial.println("p6 LOAD START");
//状態コード送信(OK)
        snd1byte(0x00);
        P6_load();
////  delay(1500);
        break;
//64h:PC-6001 LOAD ONE BYTE FROM CMT
      case 0x64:
////    Serial.println("LOAD 1BYTE START");
//  delay(1);
//状態コード送信(OK)
        snd1byte(0x00);
        load1byte();
        break;
//65h:PC-6001 LOAD ONE BYTE FROM CMT(MODE5)
      case 0x65:
////    Serial.println("LOAD 1BYTE START");
  delay(1);
//状態コード送信(OK)
        snd1byte(0x00);
        load1byte();
        break;
//66h:PC-6001 BASIC 1Byte 受信(MODE5)
      case 0x66:
////    Serial.println("BASIC SAVE 1 Byte");
  delay(1);
//状態コード送信(OK)
        snd1byte(0x00);
        save1byte();
////  delay(1500);
        break;
//67h:PC-6001 BASIC SAVE開始
      case 0x67:
////    Serial.println("BASIC SAVE START");
//状態コード送信(OK)
        snd1byte(0x00);
        bas_save_ini();
////  delay(1500);
        break;
//68h:PC-6001 BASIC 1Byte 受信
      case 0x68:
////    Serial.println("BASIC SAVE 1 Byte");
//  delay(1);
//状態コード送信(OK)
        snd1byte(0x00);
        save1byte();
////  delay(1500);
        break;
//69h:PC-6001 BASIC SAVE終了
      case 0x69:
////    Serial.println("BASIC SAVE END");
//状態コード送信(OK)
        snd1byte(0x00);
        bas_save_end();
////  delay(1500);
        break;

      default:
//状態コード送信(CMD ERROR)
        snd1byte(0xF4);
    }
  } else {
//状態コード送信(ERROR)
    snd1byte(0xF0);
    sdinit();
  }
}
